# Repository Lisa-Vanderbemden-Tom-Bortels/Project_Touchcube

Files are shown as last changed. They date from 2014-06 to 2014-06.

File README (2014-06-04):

Hier zijn alle bestanden terug te vinden van het project: Project Touchcube van Tom Bortels en Lisa Vanderbemden,
studenten Electronica - ICT op PXL Tech in Diepenbeek

Om het programma met de sensor te kunnen gebruiken zijn er eerst een aantal kleine aanpassingen nodig.

Eerst moet er een database worden aangemaakt, dit kan lokaal of op een online server.
Het is aan te raden een MySQL database te gebruiken. Het is in principe ook mogelijk een andere database te gebruiken, maar dan moeten de References in het C# programma aangepast worden naar de juiste soort database.

De naam van de database hoor a2100359_project te zijn. Het kan ook een andere naam krijgen, mits deze naam ook aangepast wordt in Connection.cs van het C# programma
Vervolgens kan het script a2100359_project(2).sql gebruikt worden om alle tabellen aan te maken en deze te vullen met benodigde waarde.

Voor het programma gestart kan worden moet in het bestand connection.cs eerst nog de gebruikersnaam en wachtwoord van de Mysqldatabase worden ingevuld. Voor beveiligingsredenen zijn deze verwijderd uit dit bestand.
Hierna kan het C# programma gestart word. Er wordt een login gevraagd. Er is een test user met administratorrechten :
 gebruikersnaam: 10    wachtwoord: pxltech

Hierna kan het programma werken zoals voorzien.

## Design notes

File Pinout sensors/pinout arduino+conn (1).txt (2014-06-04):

kleurcode								richting: connector naar onder; 1-4 : links -> rechts

kabel(db25)		|	vinger		|	bordje(testbord)		|	connectorpins(db25)	|		arduinopins
				|				|							|						|
groenwit		|	pink top   	|		groenwit-links		|   20 					|	A8
roodwit			|	pink mid	|   	bruinwit 2			|	14					|	A2
geelzwart		|	pink bot	|		groen links			|	19					|	A7
oranjezwart		|	ring top	|		bruin1				|	17					|	A5
zwartwit		|	ring mid	|		oranjewit			|	25					|	A13
oranjewit		|	ring bot	|		bruinwit 3			|	16					|	A4
zwartgroen		|	midd top	|		blauw				|	21					| 	A9			
rozezwart		|	midd mid	|		geel				|	18					|	A6
paarswit		|	midd bot	|		oranje				|	23					|	A11
bruingrijs		|	wijs top	|		bruin 3				|	13					|	A0
grijszwart		|	wijs mid	|		blauwwit			|	24					|	A12
zwart			|	wijs bot	|		bruin 4				|	12					|	A1
roodzwart		|	duim top	|		groen rechts		|	15					|	A3
donkerblauwwit	|	duim bot	|		bruin 2				|	22					|	A10
bruin			|	VCC			|		bruinwit 4			|	1					|	5V

Buis 1								Buis2
	O leeg							O WM  24
	O VCC 1							O WT  13	
	O WB  12						O MM  18	
	O DT  15						O MT  21
	O DB  22						O RM  25
	O MB  23						O RT  17
	O RB  16						O PT  20
	O PB  19						O PM  14

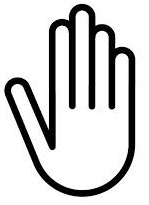
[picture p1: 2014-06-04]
C# program/Project_TouchCube/Project_TouchCube/Resources/download (1)1.jpg

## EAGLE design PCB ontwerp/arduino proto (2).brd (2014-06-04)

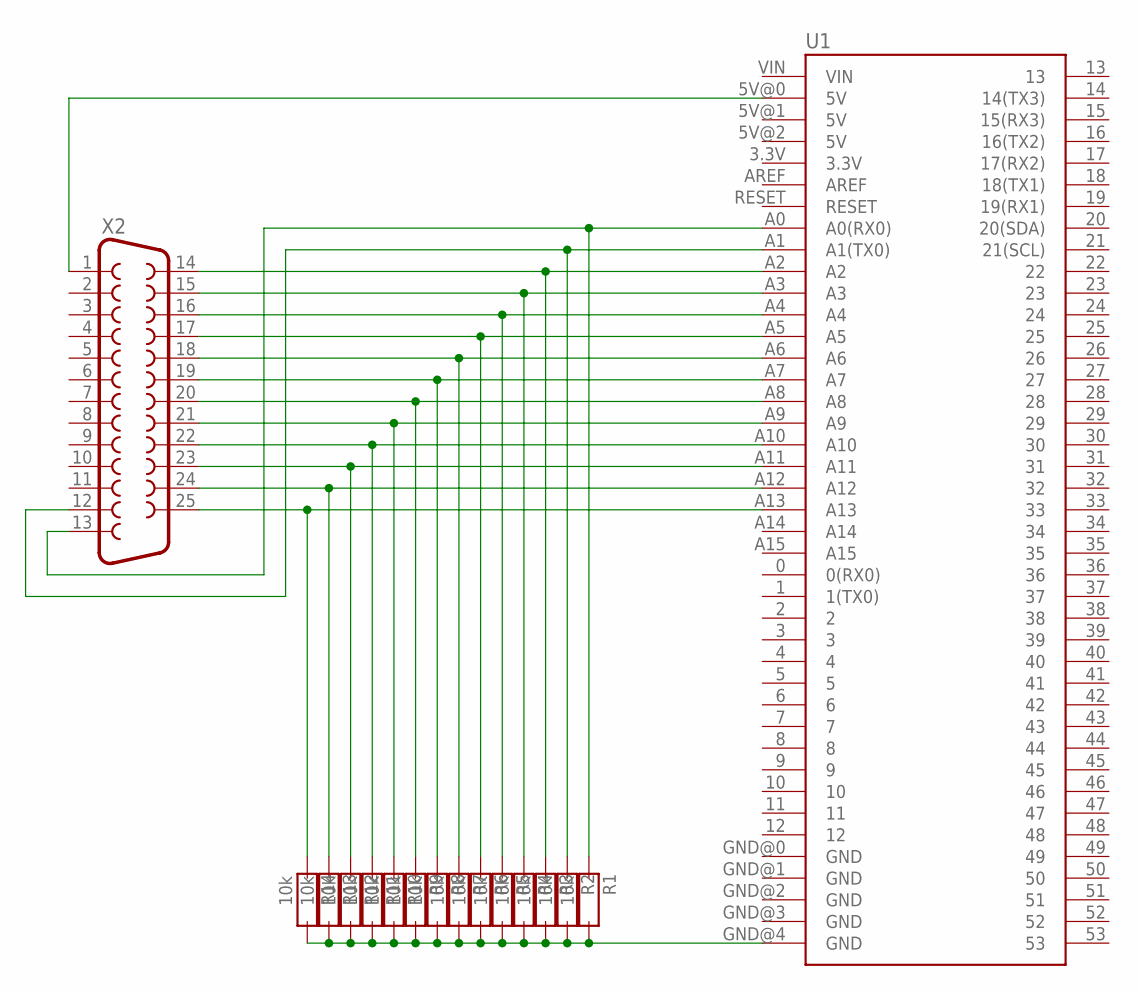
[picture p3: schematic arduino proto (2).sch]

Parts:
R1, R2, R3, R4, R5, R6, R7, R8, R9, R10, R11, R12, R13, R14: 10k; AX3
U1: ARDUINO-MEGAFULL; ARDUINO_MEGA
X2: F25HP

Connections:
unnamed: R14.1, U1.A13, X2.25
unnamed: R13.1, U1.A12, X2.24
unnamed: R12.1, U1.A11, X2.23
unnamed: R11.1, U1.A10, X2.22
unnamed: R10.1, U1.A9, X2.21
unnamed: R9.1, U1.A8, X2.20
unnamed: R8.1, U1.A7, X2.19
unnamed: R7.1, U1.A6, X2.18
unnamed: R6.1, U1.A5, X2.17
unnamed: R5.1, U1.A4, X2.16
unnamed: R4.1, U1.A3, X2.15
unnamed: R3.1, U1.A2, X2.14
unnamed: R2.1, U1.A1 (A1(TX0)), X2.12
unnamed: R1.1, U1.A0 (A0(RX0)), X2.13
unnamed: U1.5V@0 (5V), X2.1
unnamed: R1.2, R2.2, R3.2, R4.2, R5.2, R6.2, R7.2, R8.2, R9.2, R10.2, R11.2, R12.2, R13.2, R14.2, U1.GND@4 (GND)

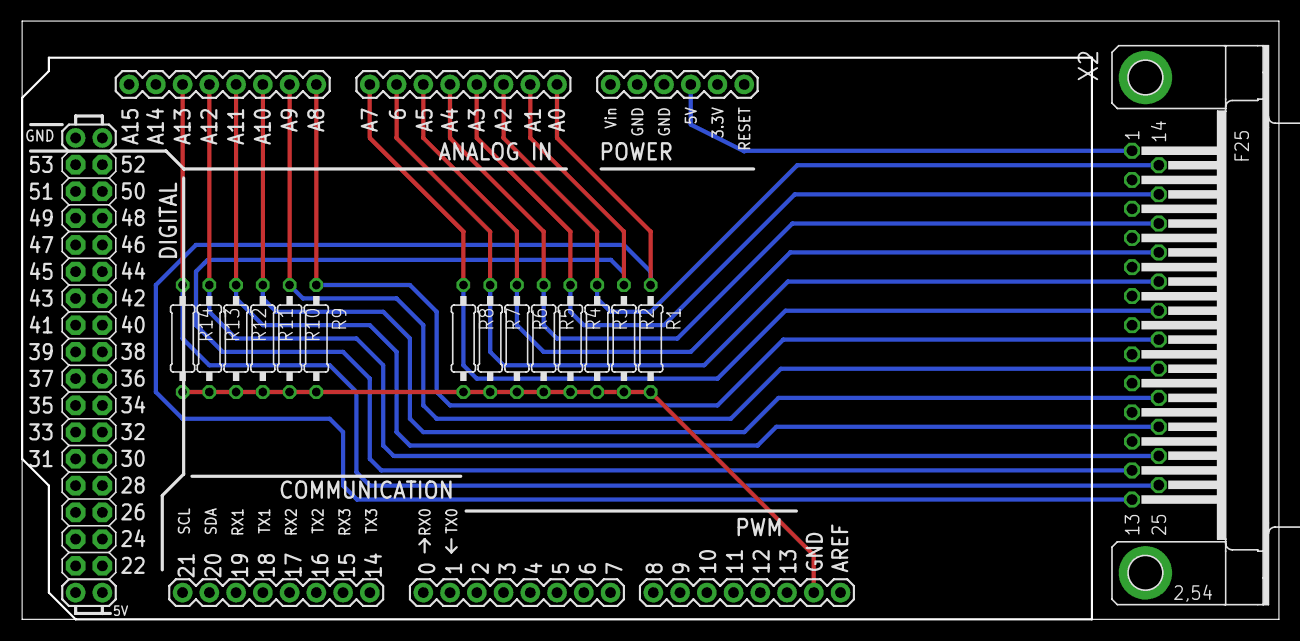
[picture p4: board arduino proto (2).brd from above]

Board: 2 copper layers, 119.4 x 56.8 mm, 16 parts (0 on the bottom side), 16 nets.

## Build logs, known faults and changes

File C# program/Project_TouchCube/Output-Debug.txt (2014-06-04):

'Project_TouchCube.vshost.exe' (Managed (v4.0.30319)): Loaded 'C:\Windows\Microsoft.Net\assembly\GAC_32\mscorlib\v4.0_4.0.0.0__b77a5c561934e089\mscorlib.dll', Skipped loading symbols. Module is optimized and the debugger option 'Just My Code' is enabled.
'Project_TouchCube.vshost.exe' (Managed (v4.0.30319)): Loaded 'C:\Windows\assembly\GAC_MSIL\Microsoft.VisualStudio.HostingProcess.Utilities\10.0.0.0__b03f5f7f11d50a3a\Microsoft.VisualStudio.HostingProcess.Utilities.dll', Skipped loading symbols. Module is optimized and the debugger option 'Just My Code' is enabled.
'Project_TouchCube.vshost.exe' (Managed (v4.0.30319)): Loaded 'C:\Windows\Microsoft.Net\assembly\GAC_MSIL\System.Windows.Forms\v4.0_4.0.0.0__b77a5c561934e089\System.Windows.Forms.dll', Skipped loading symbols. Module is optimized and the debugger option 'Just My Code' is enabled.
'Project_TouchCube.vshost.exe' (Managed (v4.0.30319)): Loaded 'C:\Windows\Microsoft.Net\assembly\GAC_MSIL\System.Drawing\v4.0_4.0.0.0__b03f5f7f11d50a3a\System.Drawing.dll', Skipped loading symbols. Module is optimized and the debugger option 'Just My Code' is enabled.
'Project_TouchCube.vshost.exe' (Managed (v4.0.30319)): Loaded 'C:\Windows\Microsoft.Net\assembly\GAC_MSIL\System\v4.0_4.0.0.0__b77a5c561934e089\System.dll', Skipped loading symbols. Module is optimized and the debugger option 'Just My Code' is enabled.
'Project_TouchCube.vshost.exe' (Managed (v4.0.30319)): Loaded 'C:\Windows\assembly\GAC_MSIL\Microsoft.VisualStudio.HostingProcess.Utilities.Sync\10.0.0.0__b03f5f7f11d50a3a\Microsoft.VisualStudio.HostingProcess.Utilities.Sync.dll', Skipped loading symbols. Module is optimized and the debugger option 'Just My Code' is enabled.
'Project_TouchCube.vshost.exe' (Managed (v4.0.30319)): Loaded 'C:\Windows\assembly\GAC_MSIL\Microsoft.VisualStudio.Debugger.Runtime\10.0.0.0__b03f5f7f11d50a3a\Microsoft.VisualStudio.Debugger.Runtime.dll', Skipped loading symbols. Module is optimized and the debugger option 'Just My Code' is enabled.
'Project_TouchCube.vshost.exe' (Managed (v4.0.30319)): Loaded 'C:\Users\Tom\documents\visual studio 2010\Projects\Project_TouchCube\Project_TouchCube\bin\Debug\Project_TouchCube.vshost.exe', Skipped loading symbols. Module is optimized and the debugger option 'Just My Code' is enabled.
'Project_TouchCube.vshost.exe' (Managed (v4.0.30319)): Loaded 'C:\Windows\Microsoft.Net\assembly\GAC_MSIL\MySql.Data\v4.0_6.8.3.0__c5687fc88969c44d\MySql.Data.dll', Skipped loading symbols. Module is optimized and the debugger option 'Just My Code' is enabled.
'Project_TouchCube.vshost.exe' (Managed (v4.0.30319)): Loaded 'C:\Windows\Microsoft.Net\assembly\GAC_MSIL\MySql.Data.Entity\v4.0_6.8.3.0__c5687fc88969c44d\MySql.Data.Entity.dll', Skipped loading symbols. Module is optimized and the debugger option 'Just My Code' is enabled.
'Project_TouchCube.vshost.exe' (Managed (v4.0.30319)): Loaded 'C:\Windows\Microsoft.Net\assembly\GAC_MSIL\System.Core\v4.0_4.0.0.0__b77a5c561934e089\System.Core.dll', Skipped loading symbols. Module is optimized and the debugger option 'Just My Code' is enabled.
'Project_TouchCube.vshost.exe' (Managed (v4.0.30319)): Loaded 'C:\Windows\Microsoft.Net\assembly\GAC_MSIL\System.Xml.Linq\v4.0_4.0.0.0__b77a5c561934e089\System.Xml.Linq.dll', Skipped loading symbols. Module is optimized and the debugger option 'Just My Code' is enabled.
'Project_TouchCube.vshost.exe' (Managed (v4.0.30319)): Loaded 'C:\Windows\Microsoft.Net\assembly\GAC_MSIL\System.Data.DataSetExtensions\v4.0_4.0.0.0__b77a5c561934e089\System.Data.DataSetExtensions.dll', Skipped loading symbols. Module is optimized and the debugger option 'Just My Code' is enabled.
'Project_TouchCube.vshost.exe' (Managed (v4.0.30319)): Loaded 'C:\Windows\Microsoft.Net\assembly\GAC_MSIL\Microsoft.CSharp\v4.0_4.0.0.0__b03f5f7f11d50a3a\Microsoft.CSharp.dll', Skipped loading symbols. Module is optimized and the debugger option 'Just My Code' is enabled.
'Project_TouchCube.vshost.exe' (Managed (v4.0.30319)): Loaded 'C:\Windows\Microsoft.Net\assembly\GAC_32\System.Data\v4.0_4.0.0.0__b77a5c561934e089\System.Data.dll', Skipped loading symbols. Module is optimized and the debugger option 'Just My Code' is enabled.
'Project_TouchCube.vshost.exe' (Managed (v4.0.30319)): Loaded 'C:\Windows\Microsoft.Net\assembly\GAC_MSIL\System.Deployment\v4.0_4.0.0.0__b03f5f7f11d50a3a\System.Deployment.dll', Skipped loading symbols. Module is optimized and the debugger option 'Just My Code' is enabled.
'Project_TouchCube.vshost.exe' (Managed (v4.0.30319)): Loaded 'C:\Windows\Microsoft.Net\assembly\GAC_MSIL\System.Xml\v4.0_4.0.0.0__b77a5c561934e089\System.Xml.dll', Skipped loading symbols. Module is optimized and the debugger option 'Just My Code' is enabled.
The thread 'vshost.NotifyLoad' (0x1c20) has exited with code 0 (0x0).
The thread '<No Name>' (0x1c58) has exited with code 0 (0x0).
The thread 'vshost.LoadReference' (0x2560) has exited with code 0 (0x0).
'Project_TouchCube.vshost.exe' (Managed (v4.0.30319)): Loaded 'C:\Users\Tom\documents\visual studio 2010\Projects\Project_TouchCube\Project_TouchCube\bin\Debug\Project_TouchCube.exe', Symbols loaded.
The thread 'vshost.RunParkingWindow' (0x19d4) has exited with code 0 (0x0).
The thread '<No Name>' (0x1c38) has exited with code 0 (0x0).
The program '[4200] Project_TouchCube.vshost.exe: Managed (v4.0.30319)' has exited with code 0 (0x0).

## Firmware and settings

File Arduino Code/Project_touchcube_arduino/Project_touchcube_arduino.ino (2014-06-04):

int lees = A0;
int lees1 = A1;
int lees2 = A2;
int lees3 = A3;
int lees4 = A4;
int lees5 = A5;
int lees6 = A6;
int lees7 = A7;
int lees8 = A8;
int lees9 = A9;
int lees10 = A10;
int lees11 = A11;
int lees12 = A12;
int lees13 = A13;

int sensorvalue = 0;

int sensormin[14];
int i;

String waarde = "";

void setup(){
  pinMode(lees,INPUT);
  pinMode(lees1,INPUT);
  pinMode(lees2,INPUT);
  pinMode(lees3,INPUT);
  pinMode(lees4,INPUT);
  pinMode(lees5,INPUT);
  pinMode(lees6,INPUT);
  pinMode(lees7,INPUT);
  pinMode(lees8,INPUT);
  pinMode(lees9,INPUT);
  pinMode(lees10,INPUT);
  pinMode(lees11,INPUT);
  pinMode(lees12,INPUT);
  pinMode(lees13,INPUT);
  
  for(i=0;i<14;i++){
    sensormin[i] = 1023;
  }
  
  //calibration
  while(millis()<5000){
    sensorvalue = analogRead(lees);
    if(sensorvalue<sensormin[0]){
      sensormin[0] = sensorvalue;
    }
      sensorvalue = analogRead(lees1);
    if(sensorvalue<sensormin[1]){
      sensormin[1] = sensorvalue;
    }
    
      sensorvalue = analogRead(lees2);
    if(sensorvalue<sensormin[2]){
      sensormin[2] = sensorvalue;
    }
    
      sensorvalue = analogRead(lees3);
    if(sensorvalue<sensormin[3]){
      sensormin[3] = sensorvalue;
    }
    
      sensorvalue = analogRead(lees4);
    if(sensorvalue<sensormin[4]){
      sensormin[4] = sensorvalue;
    }
    
      sensorvalue = analogRead(lees5);
    if(sensorvalue<sensormin[5]){
      sensormin[5] = sensorvalue;
    }
    
      sensorvalue = analogRead(lees6);
    if(sensorvalue<sensormin[6]){
      sensormin[6] = sensorvalue;
    }
    
      sensorvalue = analogRead(lees7);
    if(sensorvalue<sensormin[7]){
      sensormin[7] = sensorvalue;
    }
    
      sensorvalue = analogRead(lees8);
    if(sensorvalue<sensormin[8]){
      sensormin[8] = sensorvalue;
    }
    
      sensorvalue = analogRead(lees9);
    if(sensorvalue<sensormin[9]){
      sensormin[9] = sensorvalue;
    }
    
      sensorvalue = analogRead(lees10);
    if(sensorvalue<sensormin[10]){
      sensormin[10] = sensorvalue;
    }
    
      sensorvalue = analogRead(lees11);
    if(sensorvalue<sensormin[11]){
      sensormin[11] = sensorvalue;
    }
    
      sensorvalue = analogRead(lees12);
    if(sensorvalue<sensormin[12]){
      sensormin[12] = sensorvalue;
    }
    
      sensorvalue = analogRead(lees13);
    if(sensorvalue<sensormin[13]){
      sensormin[13] = sensorvalue;
    }
    
    
  }
  
  
  Serial.begin(9600);
}

void loop(){
  waarde = "";
  waarde += "ptc:";
  
  //DT
  sensorvalue = analogRead(lees3);
  sensorvalue = map(sensorvalue,sensormin[3],1023,0,255);
  sensorvalue = constrain(sensorvalue,0,255);
  waarde+=(String(sensorvalue)+":");
  //DB
   sensorvalue = analogRead(lees10);
   sensorvalue = map(sensorvalue,sensormin[10],1023,0,255);
   sensorvalue = constrain(sensorvalue,0,255);
  waarde+=(String(sensorvalue)+":");
  //WT
   sensorvalue = analogRead(lees);
   sensorvalue = map(sensorvalue,sensormin[0],1023,0,255);
   sensorvalue = constrain(sensorvalue,0,255);
  waarde+=(String(sensorvalue)+":");
  //WM
   sensorvalue = analogRead(lees12);
   sensorvalue = map(sensorvalue,sensormin[12],1023,0,255);
   sensorvalue = constrain(sensorvalue,0,255);
  waarde+=(String(sensorvalue)+":");
  //WB
   sensorvalue = analogRead(lees1);
   sensorvalue = map(sensorvalue,sensormin[1],1023,0,255);
   sensorvalue = constrain(sensorvalue,0,255);
  waarde+=(String(sensorvalue)+":");
  //MT
   sensorvalue = analogRead(lees9);
   sensorvalue = map(sensorvalue,sensormin[9],1023,0,255);
   sensorvalue = constrain(sensorvalue,0,255);
  waarde+=(String(sensorvalue)+":");
  //MM
   sensorvalue = analogRead(lees6);
   sensorvalue = map(sensorvalue,sensormin[6],1023,0,255);
   sensorvalue = constrain(sensorvalue,0,255);
 waarde+=(String(sensorvalue)+":");
 //MB
   sensorvalue = analogRead(lees11);
   sensorvalue = map(sensorvalue,sensormin[11],1023,0,255);
   sensorvalue = constrain(sensorvalue,0,255);
  waarde+=(String(sensorvalue)+":");
  //RT
   sensorvalue = analogRead(lees5);
   sensorvalue = map(sensorvalue,sensormin[5],1023,0,255);
   sensorvalue = constrain(sensorvalue,0,255);
  waarde+=(String(sensorvalue)+":");
  //RM
   sensorvalue = analogRead(lees13);
   sensorvalue = map(sensorvalue,sensormin[13],1023,0,255);
   sensorvalue = constrain(sensorvalue,0,255);
  waarde+=(String(sensorvalue)+":");
  //RB
   sensorvalue = analogRead(lees4);
   sensorvalue = map(sensorvalue,sensormin[4],1023,0,255);
   sensorvalue = constrain(sensorvalue,0,255);
  waarde+=(String(sensorvalue)+":");
  //PT
   sensorvalue = analogRead(lees8);
   sensorvalue = map(sensorvalue,sensormin[8],1023,0,255);
   sensorvalue = constrain(sensorvalue,0,255);
  waarde+=(String(sensorvalue)+":");
  //PM
   sensorvalue = analogRead(lees2);
   sensorvalue = map(sensorvalue,sensormin[2],1023,0,255);
   sensorvalue = constrain(sensorvalue,0,255);
  waarde+=(String(sensorvalue)+":");
  //PB
   sensorvalue = analogRead(lees7);
   sensorvalue = map(sensorvalue,sensormin[7],1023,0,255);
   sensorvalue = constrain(sensorvalue,0,255);
  waarde+=(String(sensorvalue)+":");
  
  waarde+="ptc";
  
  
  Serial.println(waarde);
  
  delay(2000);
  
}

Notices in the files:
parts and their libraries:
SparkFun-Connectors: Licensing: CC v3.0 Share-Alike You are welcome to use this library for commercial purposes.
